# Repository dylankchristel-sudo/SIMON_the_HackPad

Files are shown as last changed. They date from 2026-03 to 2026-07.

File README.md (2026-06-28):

# SIMOND 

SIMOND is a keypad designed to be usable in several applications. It has 5 keys, a rotary encoder, an OLED display, and 4 WS2812B LEDs. It uses KMK firmware.

# Features:

128x32 OLED Display  
EC11 Rotary encoder  
4 WS2812B AR LEDs

Snapchat-1873251936~2

# CAD Model:

Two parts: a case and a lid. (IDK why my PCB rendered that way). The holes will be covered with keycaps and the rotary encoder.




Made in Onshape

# PCB:

The microcontroller is actually a seeed studio XIAO rp2040. For some reason the symbol for that part was labeled wrong on the schematic and PCB editor.

Schematic  


PCB



# Firmware:

 The keys are linked to d, y, l, rgb control, and n.
  The rotary encoder controls volume (up/doen/mute)
  The OLED displays a welcome message aad layer info.
  The LEDs light up for style

# BOM:

4x Cherry MX Switches

* 5x DSA Keycaps  
* 4X M3x12mm SHCS Bolts  
* 4x WS2812B LEDs  
* 1x 0.91" 128x32 OLED Display  
* 1x EC11 Rotary Encoder  
* 1x XIAO RP2040  
* 1x Case

# Extra Stuff

:P

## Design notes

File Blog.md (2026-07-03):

# How I cooked my microcontroller

When I first soldered my XIAO onto my PCB, I put the pins through the controller and soldered the ends to the pads of the PCB. I didn't realize I also needed to solder the controller to the pins. Because of this, I left the black bracket over the area I needed to solder.

When I realized that I had messed up, I tried to pull the brackets off, but they were stuck(probably from getting accidentally melted during the first solder attempt), so I tried to clip the bracket off with wire cutters.

This went terribly. I clipped one of the resistors clean off the controller. I thought I was totally cooked.

After I did some research, I realized I could work around the issue in my code. HOWEVER, when I was debugging later, I realized the code wouldn't run properly until I soldered it together properly.
So ever so carefully I used the wire cutters again(I'll never learn ig) to remove the brackets. And it worked! I was able to solder it up with minimal issues.

So I go to plug it in aaaaand nothing. No connection. No lights. I bricked it. I can only assume my soldering iron cooked the chip and broke the internals.

# What Now?

I've ordered a new XAIO RP 2040 board and just have to recode it and replace the broken board with the new one. The only problem now is that my solder job was a mess, and it's going to be tough to remove the first board.
But I trust in the power of YouTube tutorials to help me fix this in time.

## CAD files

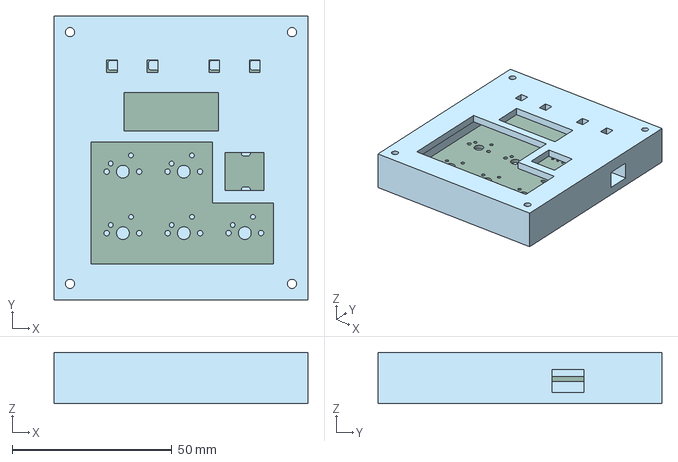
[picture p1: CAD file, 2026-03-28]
CAD/Assembly 1.step
79.4 x 88.7 x 16.0 mm
Hack Pad_PCB

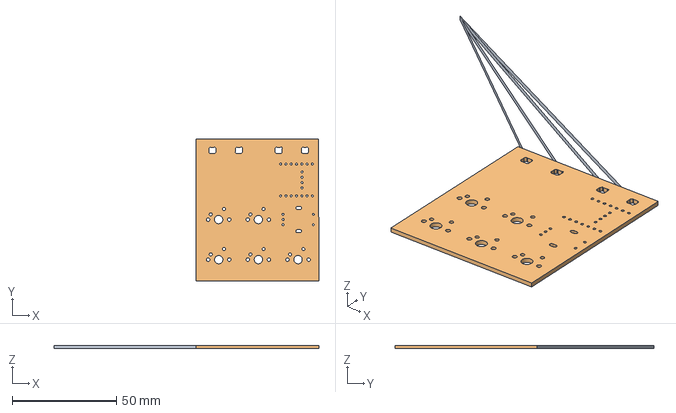
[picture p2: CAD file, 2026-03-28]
Production/CAD production/PCB.step
127.2 x 124.4 x 1.51 mm
Hack Pad_PCB x 5

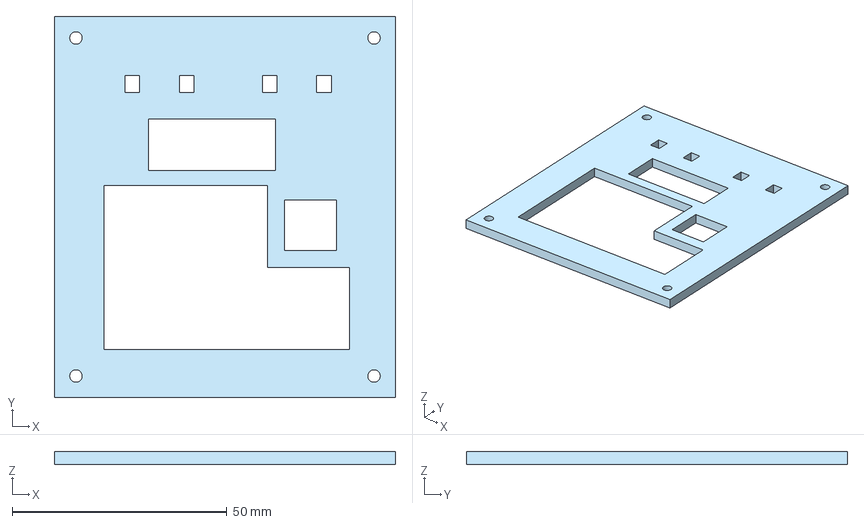
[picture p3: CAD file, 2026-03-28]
Production/CAD production/Top.step
79.4 x 88.7 x 3.00 mm

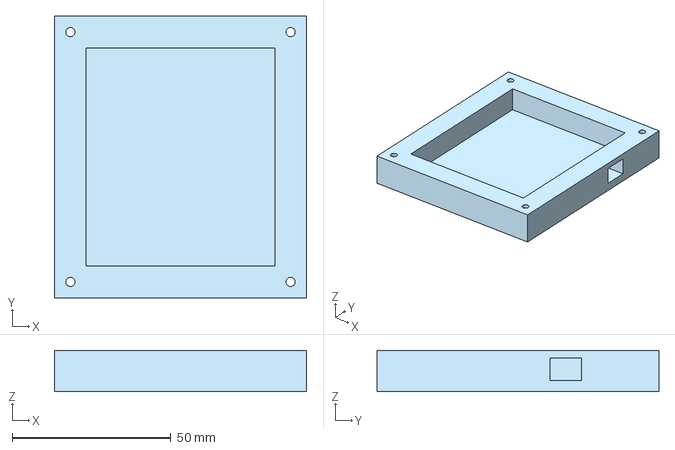
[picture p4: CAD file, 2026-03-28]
Production/CAD production/Bottom.step
79.4 x 88.7 x 13.0 mm

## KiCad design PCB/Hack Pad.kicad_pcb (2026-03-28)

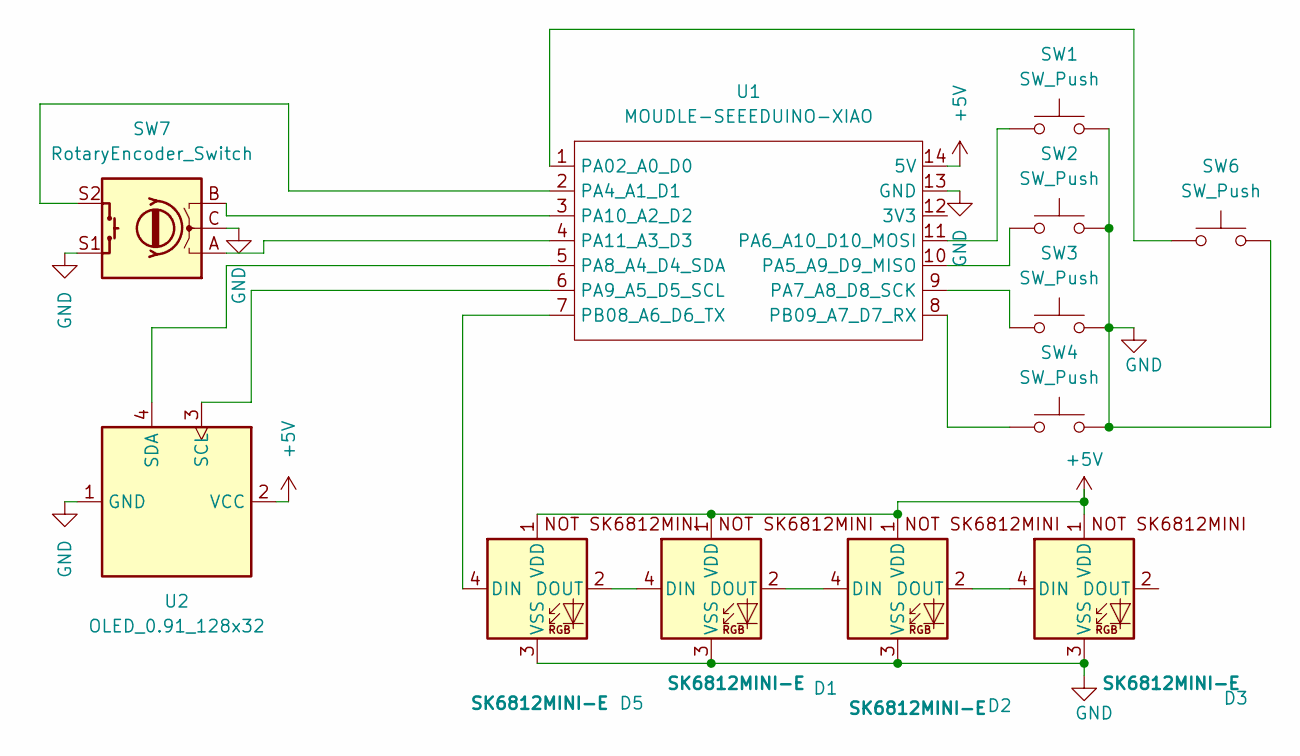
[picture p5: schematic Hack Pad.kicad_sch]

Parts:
D1, D2, D3, D5: SK6812MINI-E; SK6812MINI-E_fixed
SW1, SW2, SW3, SW4, SW6: SW_Push; SW_Cherry_MX_1.00u_PCB
SW7: RotaryEncoder_Switch; RotaryEncoder_Alps_EC11E-Switch_Vertical_H20mm
U1: MOUDLE-SEEEDUINO-XIAO; XIAO-Generic-Hybrid-14P-2.54-21X17.8MM
U2: OLED_0.91_128x32; Adafruit_SSD1306

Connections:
+5V: D1.1 (VDD), D2.1 (VDD), D3.1 (VDD), D5.1 (VDD), U1.14 (5V), U2.2 (VCC)
GND: D1.3 (VSS), D2.3 (VSS), D3.3 (VSS), D5.3 (VSS), SW1.2, SW2.2, SW3.2, SW4.2, SW6.2, SW7.C, SW7.S1, U1.13 (GND), U2.1 (GND)
unnamed: D1.4 (DIN), D5.2 (DOUT)
unnamed: D1.2 (DOUT), D2.4 (DIN)
unnamed: D2.2 (DOUT), D3.4 (DIN)
unnamed: D5.4 (DIN), U1.7 (PB08_A6_D6_TX)
unnamed: SW6.1, U1.1 (PA02_A0_D0)
unnamed: SW7.S2, U1.2 (PA4_A1_D1)
unnamed: SW2.1, U1.10 (PA5_A9_D9_MISO)
unnamed: SW1.1, U1.11 (PA6_A10_D10_MOSI)
unnamed: SW3.1, U1.9 (PA7_A8_D8_SCK)
unnamed: U1.5 (PA8_A4_D4_SDA), U2.4 (SDA)
unnamed: U1.6 (PA9_A5_D5_SCL), U2.3 (SCL)
unnamed: SW7.B, U1.3 (PA10_A2_D2)
unnamed: SW7.A, U1.4 (PA11_A3_D3)
unnamed: SW4.1, U1.8 (PB09_A7_D7_RX)

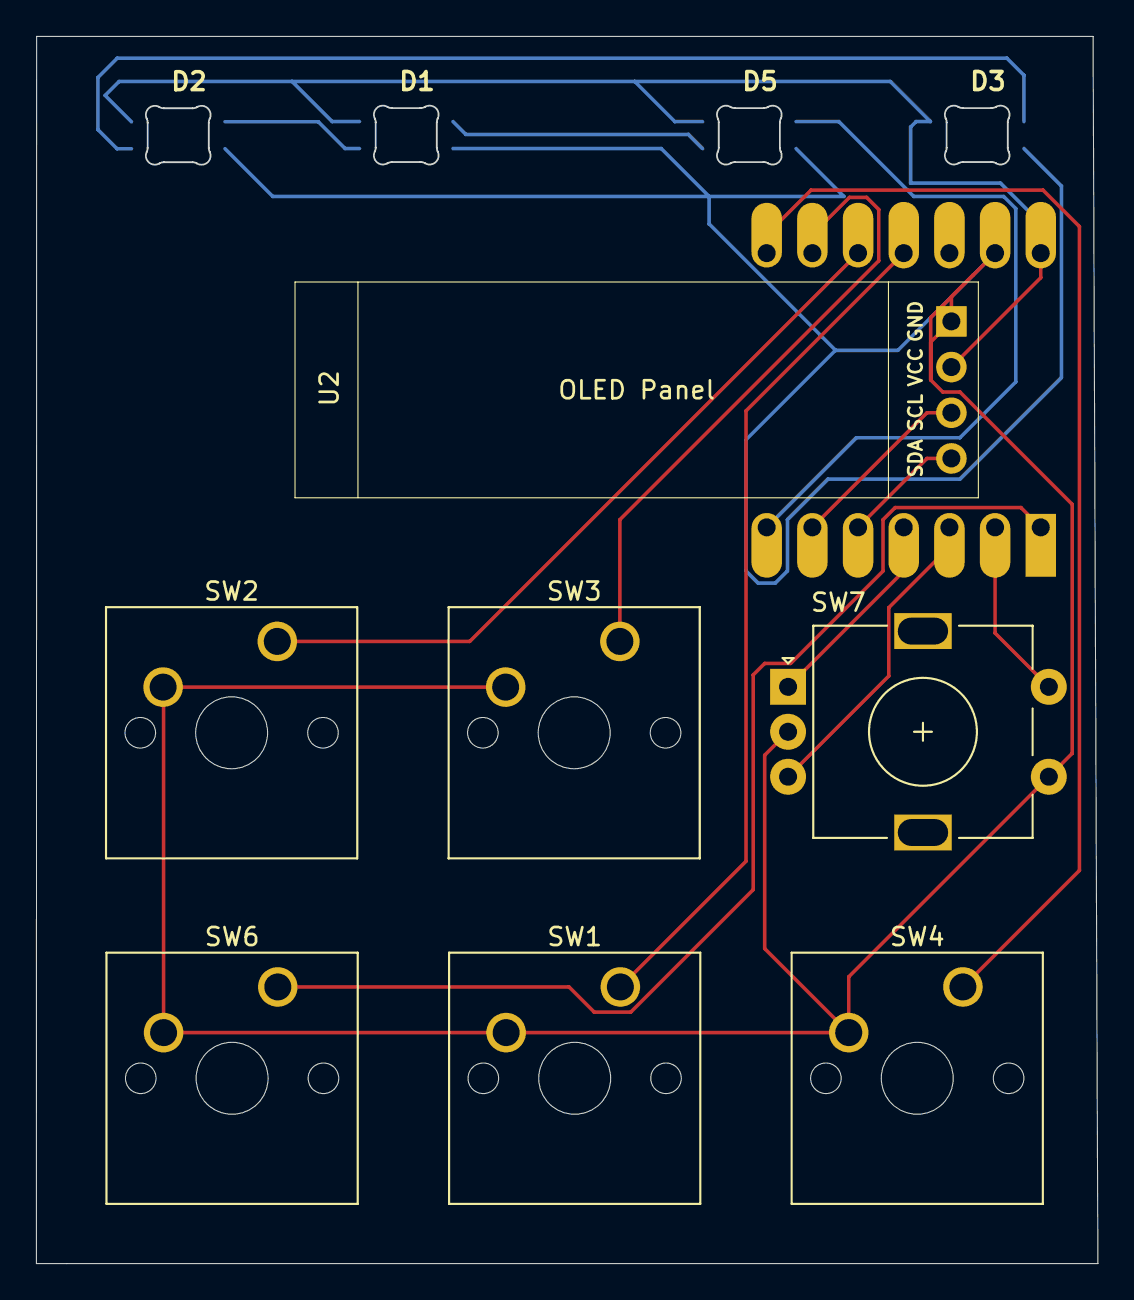
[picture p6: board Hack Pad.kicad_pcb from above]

Board: 2 copper layers, 59.0 x 68.2 mm, 12 parts (1 on the bottom side), 16 nets.

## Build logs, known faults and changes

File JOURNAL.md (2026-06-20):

Sorry in advance, I know this isn't the usual format, but I am writing this after the fact, so I'm reorganizing into steps instead of days.
# Step 1 Set Up
I installed KiCad and downloaded the libraries for the parts' footprints and symbols.
Getting the right libraries downloaded took much longer than it should have. There were days of failed downloads, designing with incorrect parts, and starting over.
Eventually, I found out the right libraries were right in front of me all along. But I learned a lot about KiCad.
# Step 2 Schematic
I decided  to put as many parts as I could into SIMOND. I opted for: 5 buttons, a rotary encoder, 4 LEDs, and an OLED display.
The display took an extra amount of energy. I had to research: which display I would have, what SCL and SDA pins are, and where they are on my display and microcontroler.
Overall, it was very rewarding to finally write the schematic.
# Step 3 Edit PCB
I transferred the schematic to the PCB Editor. I arranged the final layout of the board and wired around my own poor planning.
I had a hard time wiring everything together without overlapping traces.
This took a lot of creative and "interesting" looking traces. But the PCB looked like it should work!
# Step 4 Case
I designed the case in Onshape. The case has two main parts: a bottom and a lid. I also printed some supports to take the weight off my microcontroller.
It took several iterations to get the right lid shape. First, I placed the hole for the OLED in the wrong place. After fixing that, I realized I had put the lid too low for the rotary encoder, so the case didn't close.
My final design addresses both of these issues and should fit perfectly.
# Step 4 Assembly
I soldered my very own PCB for the first time!
It took me a while to figure out how to use my soldering iron and clean the tip properly.
Also, I didn't realize that when I put the OLED and the microcontroller on opposite sides of the same place on my board, I would have to solder around my 2 most expensive parts.
Eventually, I got it mostly soldered together. I missed a few pins because I thought I wasn't supposed to solder them. I was very wrong.
# Step 5 Firmware
I wrote KMK firmware using CircuitPython in the MU editor.
I had problems at every turn here. Before I even started, I struggled to get the board to connect to my laptop. Then I couldn't find relevant examples for the longest time. Finally, I realized while I was debugging that I needed to solder both sides of the pins on my microcontroller and OLED display.
I finally figured it out and now the board types! However, I still need to re-solder and see if my code works for the OLED display, and if that fixes the connection to my laptop issue as well.

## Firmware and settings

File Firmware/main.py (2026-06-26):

import board
import busio
import adafruit_ssd1306

from kmk.kmk_keyboard import KMKKeyboard
from kmk.keys import KC
from kmk.modules.layers import Layers
from kmk.scanners.keypad import keysScanner
from kmk.modules.macros import Press, Release, Tap, Macros
from kmk.modules.encoder import EncoderHandler
from kmk.extentions.rgb import RGB
from kmk.extentions.display import Display, TestEntry

keyboard = KMKKeyboard()

macros = Macros()
keyboard.modules.append(macros)

encoder = EncoderHandler()
keyboard.modules.append(encoder_handler)

keyboard.matrix = KeysScanner(
    pins=[board.GP4, board.GP2, board.GP27 #sw2, sw3
        board.GP26, board.GP3, board.GP1,  #sw6, sw1, sw4
]
value_when_pressed-pressed=False,
)

rgb = RGB(
    Pisel_pin=board.6
    num_pixels=4,
    val=150
    )
    keyboard.extentions.append(rgb)

encoder_handler.pins = (
    (board.GP6,  board.GP28, None, False)
)

i2c_bus = busio.I2C(
    scl=board.GP6,
    sda=board.GP7
)

display.text + [
    TextEntry(text='HELLO!', x=0, y=0)
    TextEntry(text='Layer(Ihardlyknowher)0', x=0, y=12)
]
oled = Display(
    display=adafruit_ssd1306.SSD1306_I2C(
        128,
        32,
        i2c_bus
    ),
    entries=display_text
)
keyboard.extentions.append(oled)

keyboard.keymap = [
[
    KC.MACRO(Press(KC.D),),
    
    KC.MACRO(Press(KC.Y),),

    KC.MUTE,
    
    KC.MACRO(Press(KC.L),),
    
    KC.MACRO(Press(KC.A)),
    
    KC.MACRO(Press(KC.RGB_TOG)),

    
],
]

encoder_handler.map = [
    ((KC.VOLD, KC.VOLU),)
]

if __name__ == '__main__':
    keyboard.go()

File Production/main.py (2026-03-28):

//idk what im doing this is my best atempt until I have time to figure it out properly

import board
from kmk.kmk_keyboard Import KMKKeyboard
from kmk.kays import KC
from kmk.scanner import MatrixScanner
from kmk.scanners import DiodeOrientation

Keyboard = KMKKeyBoard()

keyboard.col_pins = ('GPIO01', 'GPIOo2', 'GPIO03', 'GPIO04', 'GPIO05', 'GPIO06', 'GPIO43', 'GPIO09', GPIO08', 'GPIO07', 'GPIO44')
keyboard.row_pins = () 

keyboard.diode_orientation = DiodeOrientation.COLUMNS

keyboard.keymap = [
	[KC.ESCAPE, KC.LALT, KC.LSHIFT, KC.RCTRL]
]

if__name__ =='__main__':
	keyboard.go()

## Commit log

2026-06-20 Add project journal detailing development steps
    Documented the steps taken in the project, including setup, schematic design, PCB editing, case design, assembly, and firmware development.
2026-06-26 changed pin names on firmware
2026-07-03 Add blog post about microcontroller soldering mistake
    Documented the experience of soldering a microcontroller and the challenges faced during the process.
